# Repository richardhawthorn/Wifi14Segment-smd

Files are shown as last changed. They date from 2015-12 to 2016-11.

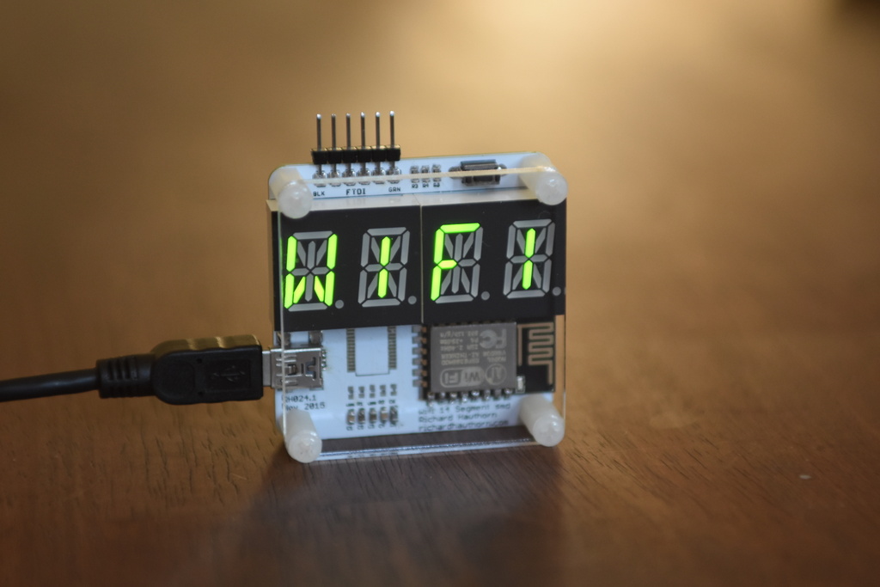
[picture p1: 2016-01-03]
images/DSC_5043.JPG

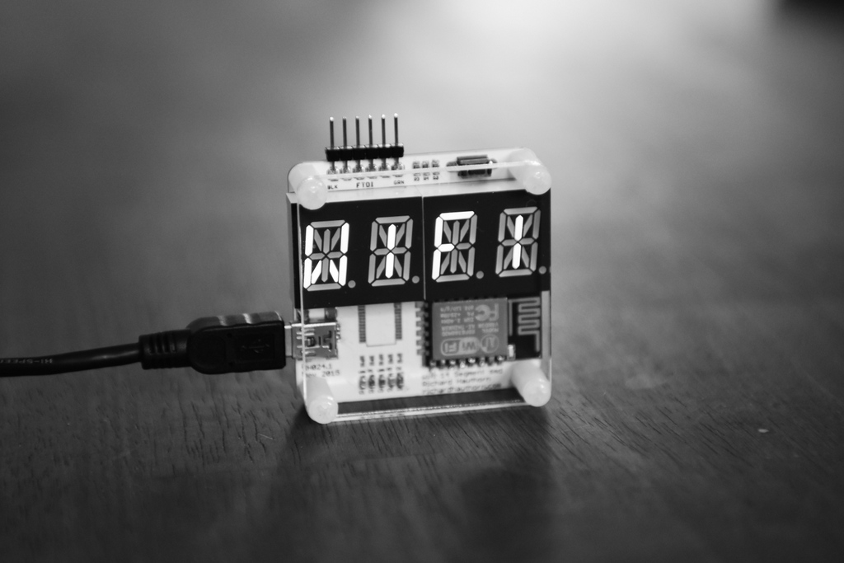
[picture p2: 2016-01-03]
images/DSC_5029.JPG

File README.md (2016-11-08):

### Features

- 0.54" 14 segment display, 4 character
- ESP8266 ESP7/12/12E Processor
- Wifi connected
- HT16K33 i2c LED driver
- FTDI chip built in
- TX & RX LED indicators
- 3.3V operation
- Mini USB power connector
- FTDI programming port
- Surface mount technology

### License

This work is licensed under a Creative Commons Attribution-ShareAlike 4.0 International License.

<br />
Designed by <a xmlns:cc="http://creativecommons.org/ns#" href="http://www.richardhawthorn.com" property="cc:attributionName" rel="cc:attributionURL" target="_blank">Richard Hawthorn</a><br />
<a rel="license" href="http://creativecommons.org/licenses/by-sa/4.0/" target="_blank">View License</a>

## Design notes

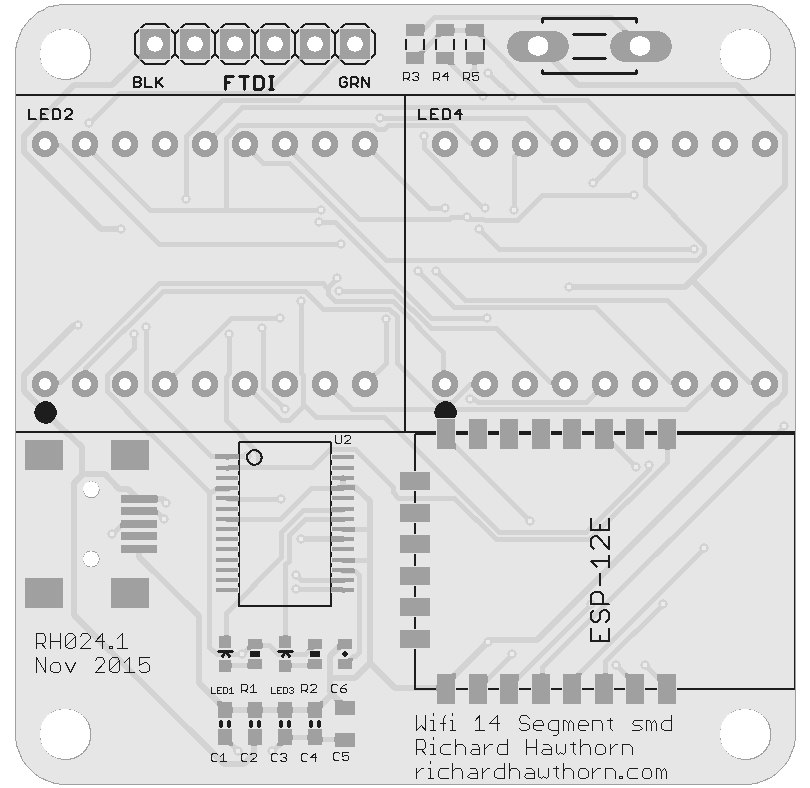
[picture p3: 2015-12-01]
images/pcb_front.png

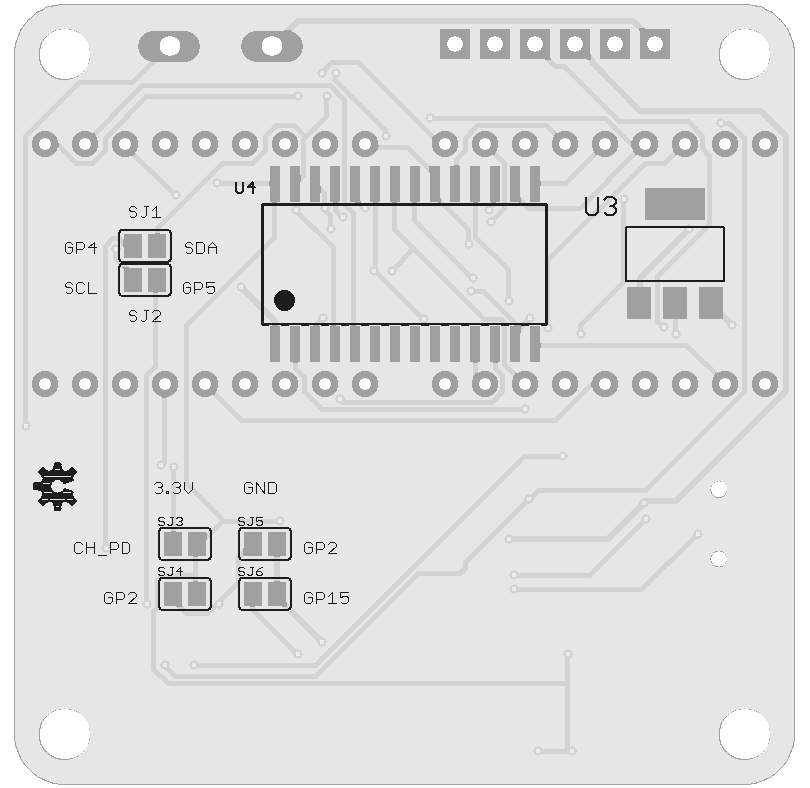
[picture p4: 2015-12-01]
images/pcb_back.png

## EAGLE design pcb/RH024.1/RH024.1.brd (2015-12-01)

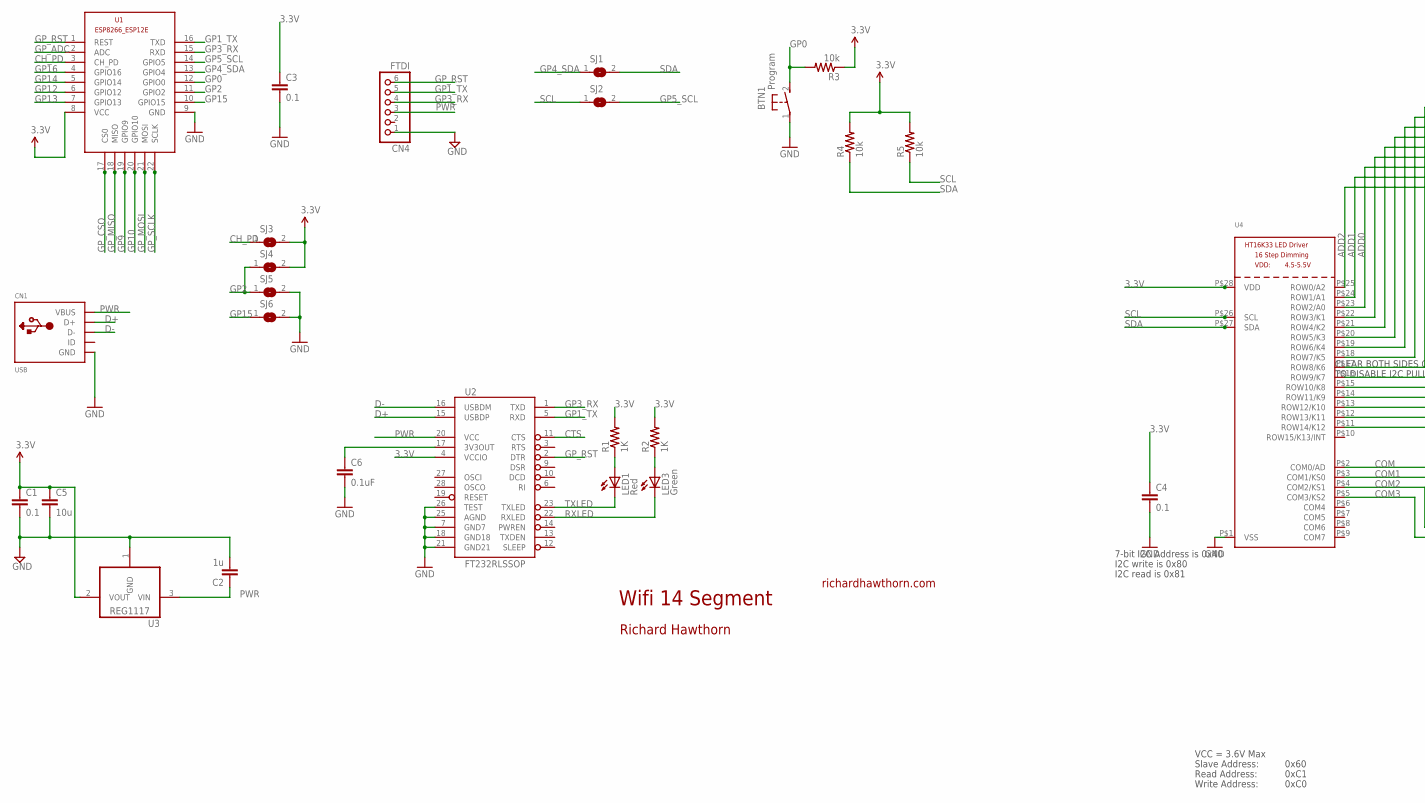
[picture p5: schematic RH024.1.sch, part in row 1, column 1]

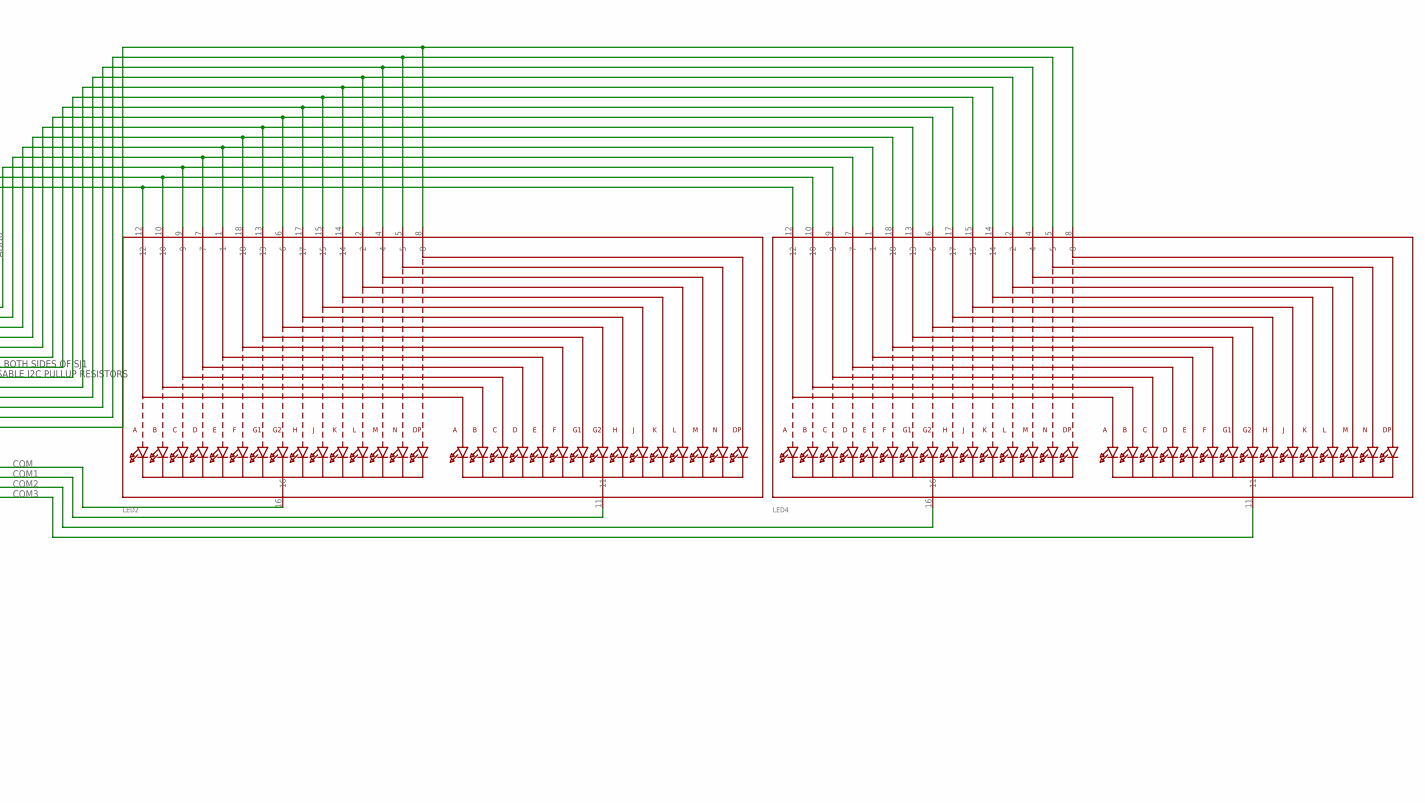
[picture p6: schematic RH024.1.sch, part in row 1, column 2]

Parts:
BTN1: Program; DTS-3
C1, C3, C4: 0.1; 0603-CAP
C2: 1u; 0603-CAP
C5: 10u; 0805-CAP
C6: 0.1uF; 0402-CAP
CN1: USB; USB-MINIB
CN4: FTDI; 1X06
LED1: Red; LED-0603
LED2, LED4: DISP_SEGMENT_STARBURST_DUAL_COMMONCATHODE; SEGMENT_STARTBUST_DUAL_KWA-541CBB
LED3: Green; LED-0603
R1, R2: 1K; 0402-RES
R3, R4, R5: 10k; 0805
SJ1, SJ2, SJ3, SJ4, SJ5, SJ6: SJ
U1: ESP8266-12EESP8266-ESP12E; ESP8266-ESP12E
U2: FT232RLSSOP; SSOP28DB
U3: REG1117; SOT223
U4: HT16K33_SOP28; SOP28_300MIL

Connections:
3.3V: C1.1, C3.1, C4.1, C5.1, R1.2, R2.2, R3.1, R4.2, R5.2, SJ3.2, SJ4.2, U1.8 (VCC), U2.4 (VCCIO), U3.2 (VOUT), U4.P$28 (VDD)
3.3VOUT: C6.1, U2.17 (3V3OUT)
ADD0: LED2.9, LED4.9, U4.P$23 (ROW2/A0)
ADD1: LED2.10, LED4.10, U4.P$24 (ROW1/A1)
ADD2: LED2.12, LED4.12, U4.P$25 (ROW0/A2)
CH_PD: SJ3.1, U1.3 (CH_PD)
COM: LED2.16, U4.P$2 (COM0/AD)
COM1: LED2.11, U4.P$3 (COM1/KS0)
COM2: LED4.16, U4.P$4 (COM2/KS1)
COM3: LED4.11, U4.P$5 (COM3/KS2)
CTS: U2.11 (CTS)
D+: CN1.D+, U2.15 (USBDP)
D-: CN1.D-, U2.16 (USBDM)
GND: BTN1.1, C1.2, C2.2, C3.2, C4.2, C5.2, C6.2, CN1.GND, CN4.1, SJ5.2, SJ6.2, U1.9 (GND), U2.7 (GND7), U2.18 (GND18), U2.21 (GND21), U2.25 (AGND), U2.26 (TEST), U3.1 (GND), U4.P$1 (VSS)
GP0: BTN1.2, R3.2, U1.12 (GPIO0)
GP1_TX: CN4.5, U1.16 (TXD), U2.5 (RXD)
GP2: SJ4.1, SJ5.1, U1.11 (GPIO2)
GP3_RX: CN4.4, U1.15 (RXD), U2.1 (TXD)
GP4_SDA: SJ1.1, U1.13 (GPIO4)
GP5_SCL: SJ2.2, U1.14 (GPIO5)
GP9: U1.19 (GPIO9)
GP10: U1.20 (GPIO10)
GP12: U1.6 (GPIO12)
GP13: U1.7 (GPIO13)
GP14: U1.5 (GPIO14)
GP15: SJ6.1, U1.10 (GPIO15)
GP16: U1.4 (GPIO16)
GP_ADC: U1.2 (ADC)
GP_CSO: U1.17 (CS0)
GP_MISO: U1.18 (MISO)
GP_MOSI: U1.21 (MOSI)
GP_RST: CN4.6, U1.1 (REST), U2.2 (DTR)
GP_SCLK: U1.22 (SCLK)
unnamed: LED1.A, R1.1
unnamed: LED3.A, R2.1
unnamed: LED2.7, LED4.7, U4.P$22 (ROW3/K1)
unnamed: LED2.1, LED4.1, U4.P$21 (ROW4/K2)
unnamed: LED2.18, LED4.18, U4.P$20 (ROW5/K3)
unnamed: LED2.13, LED4.13, U4.P$19 (ROW6/K4)
unnamed: LED2.6, LED4.6, U4.P$18 (ROW7/K5)
unnamed: LED2.17, LED4.17, U4.P$17 (ROW8/K6)
unnamed: LED2.15, LED4.15, U4.P$16 (ROW9/K7)
unnamed: LED2.14, LED4.14, U4.P$15 (ROW10/K8)
unnamed: LED2.2, LED4.2, U4.P$14 (ROW11/K9)
unnamed: LED2.4, LED4.4, U4.P$13 (ROW12/K10)
unnamed: LED2.5, LED4.5, U4.P$12 (ROW13/K11)
unnamed: LED2.8, LED4.8, U4.P$11 (ROW14/K12)
PWR: C2.1, CN1.VBUS, CN4.3, U2.20 (VCC), U3.3 (VIN)
RXLED: LED3.C, U2.22 (RXLED)
SCL: R5.1, SJ2.1, U4.P$26 (SCL)
SDA: R4.1, SJ1.2, U4.P$27 (SDA)
TXLED: LED1.C, U2.23 (TXLED)

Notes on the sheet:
Wifi 14 Segment
richardhawthorn.com
Richard Hawthorn
CLEAR BOTH SIDES OF SJ1
TO DISABLE I2C PULLUP RESISTORS
7-bit I2C Address is 0x40
I2C write is 0x80
I2C read is 0x81
VCC = 3.6V Max
Read Address:
Write Address:
Slave Address:
0x60
0xC1
0xC0

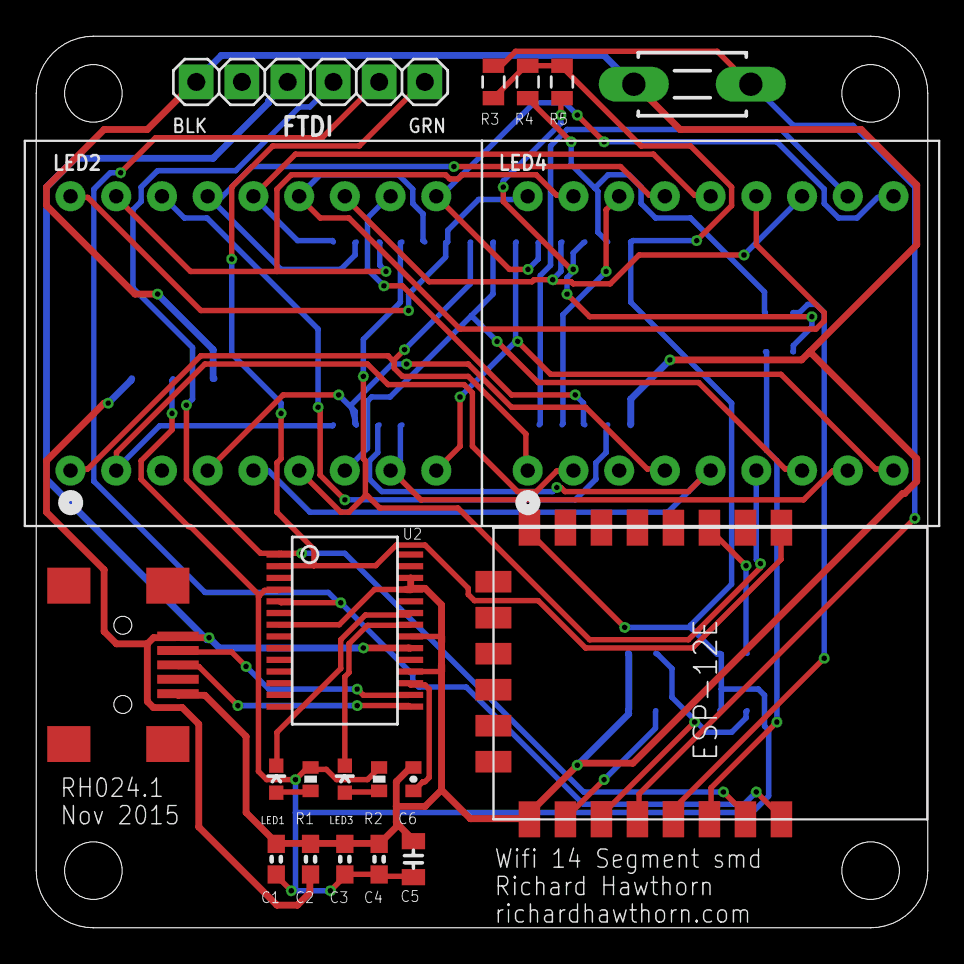
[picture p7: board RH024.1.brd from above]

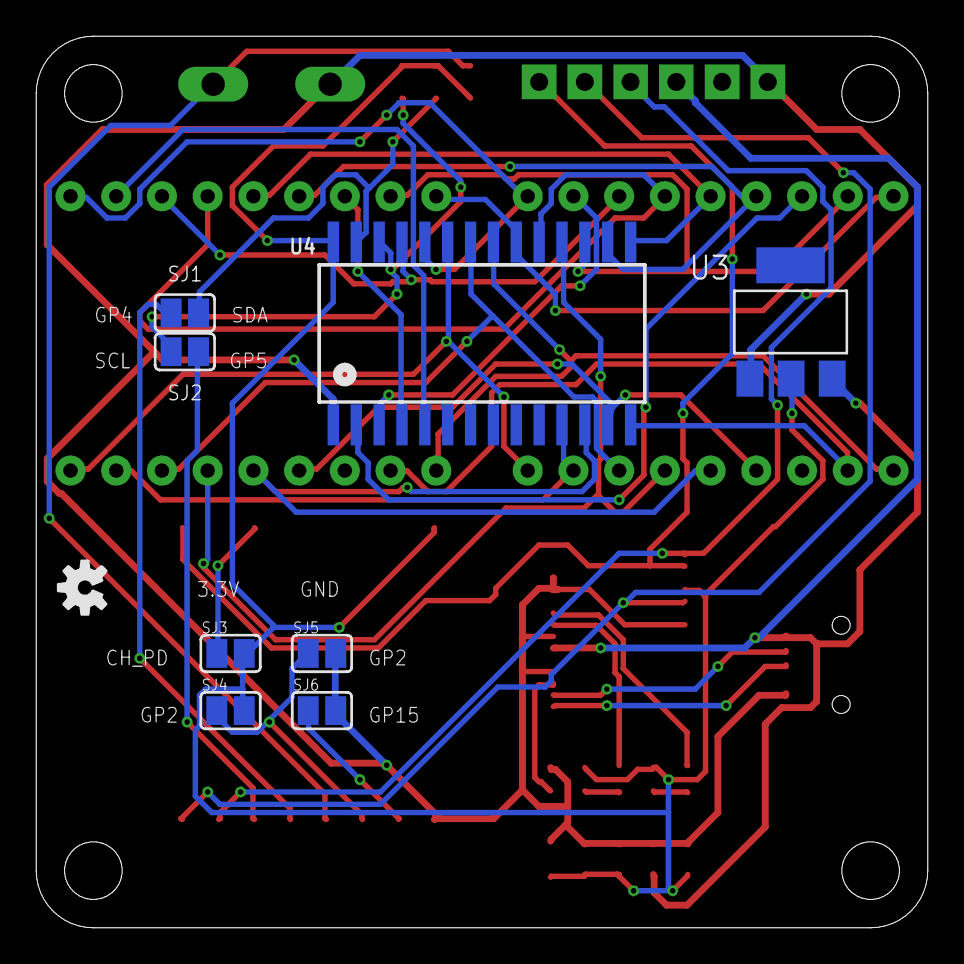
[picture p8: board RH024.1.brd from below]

Board: 2 copper layers, 49.5 x 49.5 mm, 29 parts (9 on the bottom side), 40 nets.

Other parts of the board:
U$3: OSHW-LOGO-S

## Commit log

2015-12-01 add first version of pcb
    [RH024.1.brd, RH024.1.sch]
2015-12-01 update position of usb connector
    [RH024.1.brd]

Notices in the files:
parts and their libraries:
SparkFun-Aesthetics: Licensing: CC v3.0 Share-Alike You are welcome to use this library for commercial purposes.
